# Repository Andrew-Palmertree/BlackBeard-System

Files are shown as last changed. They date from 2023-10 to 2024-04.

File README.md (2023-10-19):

# Blackbeard-System
This code is for our secure package delivery system, The Blackbeard System. This code will include object and facial recognition along with code for our servo control.

The idea behind Blackbeard is that it will allow delivered packages to end up securely inside of your home versus being left on your porch or inside some clunky metal box. The BlackBeard system incorporates a front door with a package drop located in the lower half of the door, which will drop the package in front of the front door inside of the home. It can fit packages equal to or smaller than 18x20. A camera with the system will be used to detect delivery drivers using artificial intelligence. Upon detection, the chute will open automatically for the delivery driver. The delivery man can put your package inside, then it will sense when no more packages are being delivered and automatically close, dropping the packages inside of the Blackbeard owner’s home. 
This product has space in quite a large market, to be installed on existing homes by DIYers or professional installation by contractors, or with over 1.8 million houses being built a year. This can also be installed on homes being newly built. As a company we will offer basic dimensions and different door materials, or interested customers can request custom dimensions to match their home.
The biggest areas of focus on this project are being able to depict delivery drivers using object recognition and interfacing the servo motors that control the package slip at the bottom of the front door. 
Time permitting, we would also like to implement a type of keyless entry into the home. This method would involve facial recognition of residents (utilizing the same camera for package deliveries) and/or a wireless entry system that unlocks the door when a keyfob is within proximity of the door (similar to keyless entry on modern automobiles). Despite our desire to add this additional feature, the main focus of the project is to get the package delivery system fully functional before pursuing any additional features. 

The goal of our proof of concept is to get the backend code fully functional with the servo motors, camera, & motion sensor interfaced properly with the Raspberry Pi. We plan to use a Raspberry Pi 3b+ for demonstration purposes, and it is likely we will fabricate our own PCB with a microcontroller when it comes time to create our prototype. We plan to implement computer vision with the camera and Raspberry Pi to begin training our system to detect delivery drivers and to recognize different faces. The system will be programmed using either Python or C++ depending on the route we choose to take in terms of an object recognition library. The primary goal is to get the package delivery system functional first, and time permitting we will pursue our secondary goal of creating a functional keyless entry system into the home. Below is a shortened, itemized list of what we want to be able to accomplish in our proof of concept. More detail into the major components is covered later on in this section. It is worth noting that we plan on testing all the components individually.
- Successfully interface components with Raspberry Pi
- Train a neural network to recognize delivery drivers with packages
- Camera is able to transmit real-time images to the Raspberry Pi
- Be able to trigger opening/closing of the package chute upon detection of a delivery driver
- Motion sensor is able to successfully detect motion inside the package chute
- After a period of time with no new motion detected, the chute will close

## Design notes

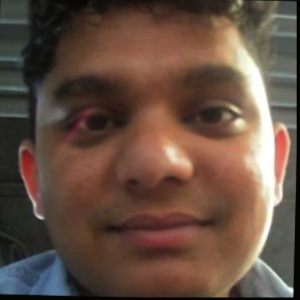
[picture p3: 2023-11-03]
Face_Recognition/pubfig/train/Parbin/cascade_images4_49.jpg

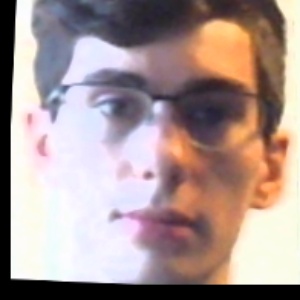
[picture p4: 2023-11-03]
Face_Recognition/Andrew/Andrew_cropped/cascade_images17_35.jpg

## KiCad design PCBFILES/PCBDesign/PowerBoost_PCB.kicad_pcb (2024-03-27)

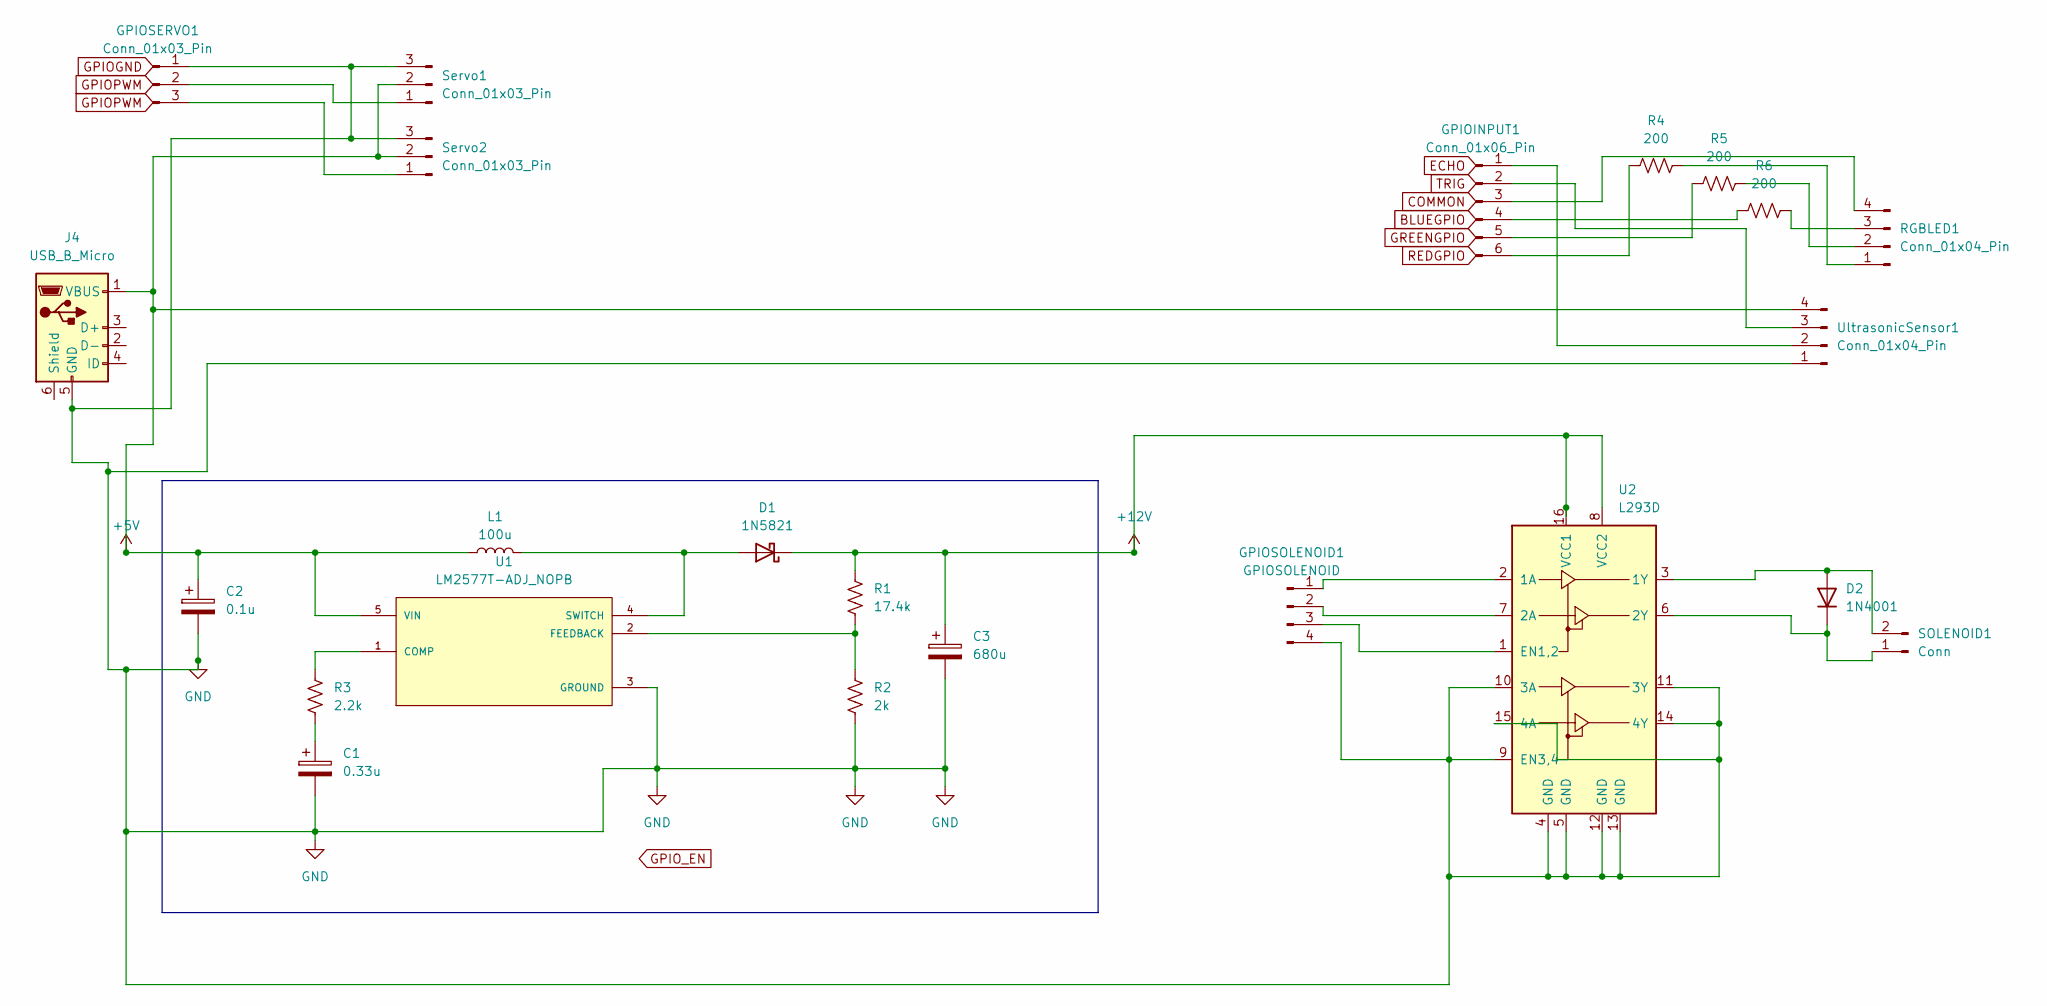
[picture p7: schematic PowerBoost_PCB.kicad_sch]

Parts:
C1: 0.33u; CP_Radial_D5.0mm_P2.50mm
C2: 0.1u; CP_Radial_D5.0mm_P2.50mm
C3: 680u; CP_Radial_D10.0mm_P5.00mm
D1: 1N5821; D_DO-201AD_P15.24mm_Horizontal
D2: 1N4001; D_DO-41_SOD81_P10.16mm_Horizontal
GPIOINPUT1: Conn_01x06_Pin
GPIOSERVO1: Conn_01x03_Pin
GPIOSOLENOID1: GPIOSOLENOID; JST_EH_B4B-EH-A_1x04_P2.50mm_Vertical
J4: USB_B_Micro
L1: 100u; L_Radial_D8.7mm_P5.00mm_Fastron_07HCP
R1: 17.4k; R_Axial_DIN0204_L3.6mm_D1.6mm_P7.62mm_Horizontal
R2: 2k; R_Axial_DIN0204_L3.6mm_D1.6mm_P7.62mm_Horizontal
R3: 2.2k; R_Axial_DIN0204_L3.6mm_D1.6mm_P7.62mm_Horizontal
R4, R5, R6: 200; R_Axial_DIN0204_L3.6mm_D1.6mm_P7.62mm_Horizontal
RGBLED1: Conn_01x04_Pin
SOLENOID1: Conn; JST_EH_B2B-EH-A_1x02_P2.50mm_Vertical
Servo1, Servo2: Conn_01x03_Pin
U1: LM2577T-ADJ_NOPB; VREG_LM2577T-ADJ_NOPB; PARTREV D
U2: L293D; DIP-16_W7.62mm
UltrasonicSensor1: Conn_01x04_Pin

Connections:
+5V: C2.1, J4.1 (VBUS), L1.1, Servo1.2, Servo2.2, U1.5 (VIN), UltrasonicSensor1.4
+12V: C3.1, D1.1 (K), R1.1, U2.8 (VCC2), U2.16 (VCC1)
GND: C1.2, C2.2, C3.2, GPIOSERVO1.1, GPIOSOLENOID1.4, J4.5 (GND), R2.2, Servo1.3, Servo2.3, U1.3 (GROUND), U2.4 (GND), U2.5 (GND), U2.9 (EN3,4), U2.10 (3A), U2.11 (3Y), U2.12 (GND), U2.13 (GND), U2.14 (4Y), U2.15 (4A), UltrasonicSensor1.1
unnamed: C1.1, R3.2
unnamed: D1.2 (A), L1.2, U1.4 (SWITCH)
unnamed: D2.2 (A), SOLENOID1.2, U2.3 (1Y)
unnamed: D2.1 (K), SOLENOID1.1, U2.6 (2Y)
unnamed: GPIOINPUT1.1, UltrasonicSensor1.2
unnamed: GPIOINPUT1.2, UltrasonicSensor1.3
unnamed: GPIOINPUT1.3, RGBLED1.4
unnamed: GPIOINPUT1.4, R6.1
unnamed: GPIOINPUT1.5, R5.2
unnamed: GPIOINPUT1.6, R4.1
unnamed: GPIOSERVO1.2, Servo1.1
unnamed: GPIOSERVO1.3, Servo2.1
unnamed: GPIOSOLENOID1.1, U2.2 (1A)
unnamed: GPIOSOLENOID1.2, U2.7 (2A)
unnamed: GPIOSOLENOID1.3, U2.1 (EN1,2)
unnamed: R4.2, RGBLED1.1
unnamed: R5.1, RGBLED1.2
unnamed: R6.2, RGBLED1.3
unnamed: R3.1, U1.1 (COMP)
unnamed: R1.2, R2.1, U1.2 (FEEDBACK)

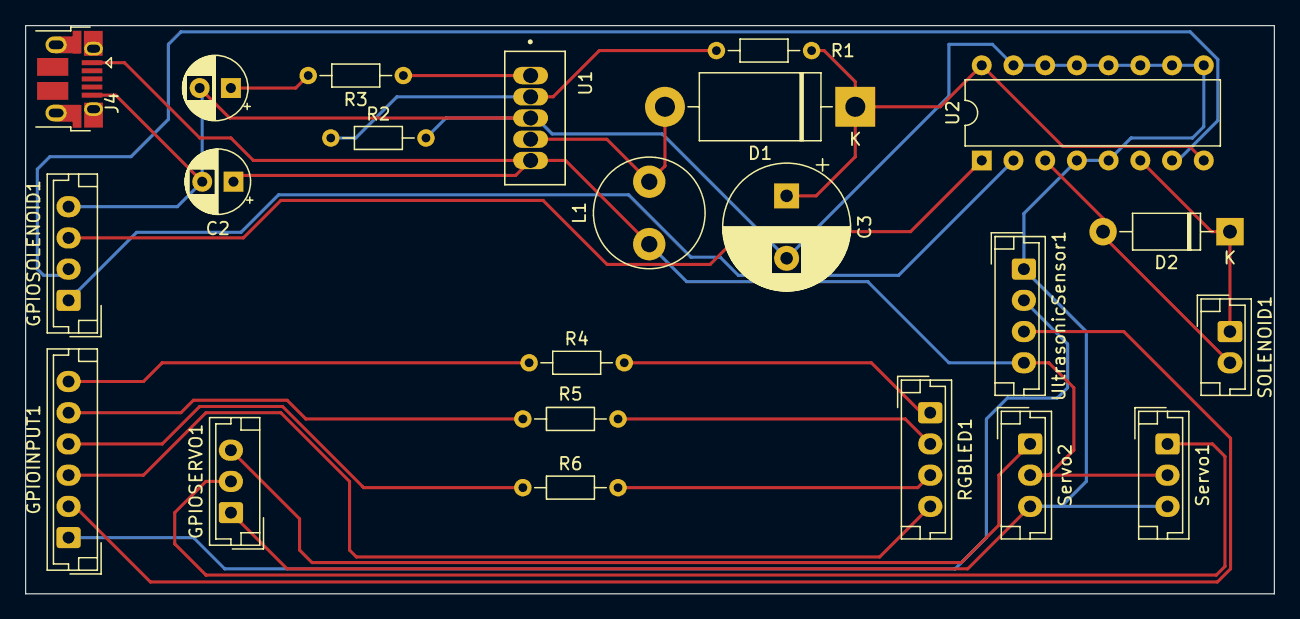
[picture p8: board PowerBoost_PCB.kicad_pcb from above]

Board: 2 copper layers, 100.0 x 45.5 mm, 23 parts (0 on the bottom side), 23 nets.

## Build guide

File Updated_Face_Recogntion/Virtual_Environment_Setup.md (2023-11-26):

#### Prepared by Andrew Palmertree for Senior Project Group Fall 2023

# UPDATED⚠️ Virtual Environment and Dependencies Setup
### This guide will allow you to install tensorflow 2.10.0,opencv 4.7.0.72, numpy 1.26.2, flatbuffers 2.0, keras_vggface, and keras_apptications.

### Note, using VNC and WinSCP will help you setup and use your reaspberry pi in the future. Instructions on how to setup VNC are at the bottom.

## 1. Project Initial Setup
### This step will get the raspberry pi working before installing the packages we need for the machine learning environment

#### This is import first step:
Make sure you are using Bullseye 11 64 bit legacy.

Go to this website incase you need to download the 64 bit OS:

https://www.raspberrypi.com/software/operating-systems/#raspberry-pi-os-64-bit

Once you have the OS installed and setup, go ahead and verify you have the Bullseye 11 OS installed:

```$cat /etc/os-release```

Look for the version_id and version to see what version of the OS you are running. If you are not running the Bullseye 11 OS then stop and install and flash the Bullseye 11 legacy OS version onto your Pi.

#### If we decide we are not using a USB camera but the socket camera you can enable it by following these steps:

1. ```$sudo raspi-config ```
2. Select option one "1 System Options"
3. Selcet option one "I1 Legacy Camera"
4. Select Enable

#### Now update your system:
```
$sudo apt-get update 
$sudo apt-get upgrade 
```
and then restarted the Pi to update all the packages installed.

#### Downgrade Python Version to 3.9.2
The next step in setting up the Raspberry Pi is to ensure that the dependencies and packages are compatible with each other. To achieve this, I downgraded Python to version 3.9.2. To do so, I ran the following commands: 

```
# Downloads Pyenv tool script and runs it in bash
$ curl https://pyenv.run | bash
$ sudo nano ~/.bashrc 
```

In the .bashrc file, I added the following lines at the end of the file: 
```
# adds /.pyenv/bin directory to your PATH environment variable
export PATH="$HOME/.pyenv/bin:$PATH" 
```
Pyenv is initialized and the shell's PATH and other environment variables are modified to prepare the shell for usage with Pyenv's shims. 

```
eval "$(pyenv init --path)"

# used to manage virtual environments
eval "$(pyenv virtualenv-init -) 
 ```

 I then restarted the terminal and installed the following packages: 
 
 ```
 $ sudo apt-get install --yes libssl-dev zlib1g-dev libbz2-dev libreadline-dev libsqlite3-dev llvm libncurses5-dev libncursesw5-dev xz-utils tk-dev libgdbm-dev lzma lzma-dev tcl-dev libxml2-dev libxmlsec1-dev libffi-dev liblzma-dev wget make opens 
 ```

Next, I updated pyenv and installed python 3.7.12: 
```
$ pyenv update
$ pyenv install –list
$ pyenv install 3.9.2 
```

After installing python 3.7.12, I set my project folder to python 3.7.12 with the following commands: 

```
$ mkdir project
$ cd project
$ pyenv local 3.9.2
$ python -V 
```
I got the following results from running python -V.

<img width="503" alt="python_version" src="https://github.com/w-410berry/Blackbeard-System/assets/66178969/9aa92d15-ab7a-4712-9a47-9c83f6dc6488">

## 2. Install and activate the virtual environment
We want to create a virtual environment so that we can isolate the Python environment and install specific packages for the project without affecting the root environment. Virtual environments are particularly useful for testing, creating backups, and enhancing security. To create a virtual environment for our real-time handwritten recognition project, I used the following commands:

```
// Creates the virtual environment
$ python3 -m pip install virtualenv
$ python3 -m virtualenv env

// activate the environment
$ source env/bin/activate 
```

Then I installed some necessary dependencies: 

```
$ sudo apt-get install -y libhdf5-dev libc-ares-dev libeigen3-dev gcc gfortran libgfortran5 libatlas3-base libatlas-base-dev libopenblas-dev libopenblas-base libblas-dev liblapack-dev cython3 libatlas-base-dev openmpi-bin libopenmpi-dev python3-dev build-essential cmake pkg-config libjpeg-dev libtiff5-dev libpng-dev libavcodec-dev libavformat-dev libswscale-dev libv4l-dev libxvidcore-dev libx264-dev libfontconfig1-dev libcairo2-dev libgdk-pixbuf2.0-dev libpango1.0-dev libgtk2.0-dev libgtk-3-dev libhdf5-serial-dev libhdf5-103 libqt5gui5 libqt5webkit5 libqt5test5 python3-pyqt5 
```

After installing the necessary dependencies, we can activate the virtual environment in the project directory by using the following command:

```
$source env/bin/activate
```

Below is a demonstration that the virtual environment can be activated through the project directory.

![image](https://github.com/w-410berry/Blackbeard-System/assets/66178969/0ebe2ba1-08fd-4eb6-865a-93bf20dab3c8)

## 3. Installing Packages in Virtual Environment 
Next, we must install the packages required for the virtual environment.To install TensorFlow 2.10.0.

You can get the tensorflow 2.10.0 file from the following commands:

```
# uninstall any previous versions of TensorFlow
$ python3 -m pip uninstall tensorflow

# Install TensorFlow 2.10.0 with the wheel file
$ pip install tensorflow==2.10.0

# Fix any other dependency issues you may have before going forward.
```

#### I then installed OpenCV:
#### Note the following
#### Time command keeps track how long your command is running and will print the results at the end
#### There are many version of opencv
1. opencv-python
2. opencv-contrib-python
3. opencv-python-headless
4. opencv-contrib-python-headless
#### Options 3 and 4 are for server (headless) environments
#### Options 1 and 2 for standard desktop environments
#### opencv-python: Main modules
#### opencv-contrib-python: Full package which contains both main modules and extra modules
#### for the cascade facial recognition we need the opencv-contrib-python:
```
# Install opencv-contrib-python (took 152 minutes on the raspberry pi 4 32 bit but with 64 bit took less than 2 minutes)
# As long as there is no error and says building the wheel then just keep waiting
$ time pip install "opencv-contrib-python<4.8"

# I then upgrade numpy to be compatible with cv2 to version 1.26.0.
$ pip install numpy==1.26.2

# Install some packages for the ResNet model:
pip install git+https://github.com/rcmalli/keras-vggface.git

pip install keras_apptications

Now to be able to convert from tensorflow to tensorflow lite I had to change flatbuffers version to 2.0:
pip install flatbuffers==2.0

# Now that TensorFlow and OpenCV is installed, I verified that I could import them by running the following commands in the Python3 shell:
$ python3 
>>> import tensorflow as tf
>>> tf._version_
>>> import cv2
>>> cv2._version_
>>> import keras_vggface
# to exit run exit() or quit()
```

If you are using the a pi camera install their packages:
```
# install picamera package
$ pip install picamera
```

## 4. (optional) Setting up VNC to see you raspberry pi display on your laptop

Make sure VNC is on your Pi. There should be an icon on the top right with the big "R" symbol or go to the "internet" tab at the top left and click VNC viewer. 
If VNC viewer is not shown then follow a online guide to install VNC viewer sever on the Pi. It should already be installed on your Pi.

<img width="546" alt="VNC_1" src="https://github.com/w-410berry/Blackbeard-System/assets/66178969/32ad97e4-4dc8-4e61-ad5d-160cbe421f27">

Once you know VNC server is installed then follow the following steps:

#### ON THE RASPBERRY PI:

To enable VNC, I entered 
```
$sudo raspi-config
```
in the terminal and navigated to "Interface Options" >>> "VNC" >>> "enable".

Note: To see the Pi Camera remotely I had to go to the server Raspberry Pi VNC and press: 
#### menu (three lines on the top right) >>> options >>> Troubleshooting >>> Enable direct capture mode.

<img width="540" alt="VNC_2" src="https://github.com/w-410berry/Blackbeard-System/assets/66178969/914d3148-9e92-4146-9e23-2282fc0cee6c">

#### ON THE COMPUTER:

Next, I installed the VNC client on my desktop computer, which enabled my laptop to connect to the Raspberry Pi VNC server. After installing the VNC client on my laptop, I created a new connection by navigating to 
#### "File" >>> "New Connection" in the VNC client. 
#### OR press (ctrl + n)
I then entered the Raspberry Pi server's IP address, hostname, and password to establish the connection. Finally, I was able to successfully connect to the server and view the Raspberry Pi desktop screen.  

## Thank you! I hope you were able to follow along and complete the setup.

# Happy Coding :) 🙌

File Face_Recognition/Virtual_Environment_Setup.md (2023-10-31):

#### Prepared by Andrew Palmertree for Senior Project Group Fall 2023

# Virtual Environment and Dependencies Setup
### This guide will allow you to install tensorflow 2.5.0, Keras 2.4.3, and opencv 4.7.0.72

### Note, using VNC and WinSCP will help you setup and use your reaspberry pi in the future. Instructions on how to setup VNC are at the bottom.

## 1. Project Initial Setup
### This step will get the raspberry pi working before installing the packages we need for the machine learning environment

#### This is import first step:
Make sure you have the latest version of the Raspberry Pi OS. As of creating this I am using Bullseye 11:

```$cat /etc/os-release```

Look for the version_id and version to see what version of the OS you are running. If you are not running the lastest OS then stop and install and flash the newest OS version onto your Pi.

#### If we decide we are not using a USB camera but the socket camera you can enable it by following these steps:

1. ```$sudo raspi-config ```
2. Select option one "1 System Options"
3. Selcet option one "I1 Legacy Camera"
4. Select Enable

#### Now update your system:
```
$sudo apt-get update 
$sudo apt-get upgrade 
```
and then restarted the Pi to update all the packages installed.

#### Downgrade Python Version to 3.7.12
The next step in setting up the Raspberry Pi is to ensure that the dependencies and packages are compatible with each other. To achieve this, I downgraded Python to version 3.7.12. To do so, I ran the following commands: 

```
# Downloads Pyenv tool script and runs it in bash
$ curl https://pyenv.run | bash
$ sudo nano ~/.bashrc 
```

In the .bashrc file, I added the following lines at the end of the file: 
```
# adds /.pyenv/bin directory to your PATH environment variable
export PATH="$HOME/.pyenv/bin:$PATH" 
```
Pyenv is initialized and the shell's PATH and other environment variables are modified to prepare the shell for usage with Pyenv's shims. 

```
eval "$(pyenv init --path)"

# used to manage virtual environments
eval "$(pyenv virtualenv-init -) 
 ```

 I then restarted the terminal and installed the following packages: 
 
 ```
 $ sudo apt-get install --yes libssl-dev zlib1g-dev libbz2-dev libreadline-dev libsqlite3-dev llvm libncurses5-dev libncursesw5-dev xz-utils tk-dev libgdbm-dev lzma lzma-dev tcl-dev libxml2-dev libxmlsec1-dev libffi-dev liblzma-dev wget make opens 
 ```

Next, I updated pyenv and installed python 3.7.12: 
```
$ pyenv update
$ pyenv install –list
$ pyenv install 3.7.12 
```

After installing python 3.7.12, I set my project folder to python 3.7.12 with the following commands: 

```
$ mkdir project
$ cd project
$ pyenv local 3.7.12
$ python -V 
```
I got the following results from running python -V.

<img width="503" alt="python_version" src="https://github.com/w-410berry/Blackbeard-System/assets/66178969/9aa92d15-ab7a-4712-9a47-9c83f6dc6488">

## 2. Install and activate the virtual environment
We want to create a virtual environment so that we can isolate the Python environment and install specific packages for the project without affecting the root environment. Virtual environments are particularly useful for testing, creating backups, and enhancing security. To create a virtual environment for our real-time handwritten recognition project, I used the following commands:

```
// Creates the virtual environment
$ python3 -m pip install virtualenv
$ python3 -m virtualenv env

// activate the environment
$ source env/bin/activate 
```

Then I installed some necessary dependencies: 

```
$ sudo apt-get install -y libhdf5-dev libc-ares-dev libeigen3-dev gcc gfortran libgfortran5 libatlas3-base libatlas-base-dev libopenblas-dev libopenblas-base libblas-dev liblapack-dev cython3 libatlas-base-dev openmpi-bin libopenmpi-dev python3-dev build-essential cmake pkg-config libjpeg-dev libtiff5-dev libpng-dev libavcodec-dev libavformat-dev libswscale-dev libv4l-dev libxvidcore-dev libx264-dev libfontconfig1-dev libcairo2-dev libgdk-pixbuf2.0-dev libpango1.0-dev libgtk2.0-dev libgtk-3-dev libhdf5-serial-dev libhdf5-103 libqt5gui5 libqt5webkit5 libqt5test5 python3-pyqt5 
```

After installing the necessary dependencies, we can activate the virtual environment in the project directory by using the following command:

```
$source env/bin/activate
```

Below is a demonstration that the virtual environment can be activated through the project directory.

![image](https://github.com/w-410berry/Blackbeard-System/assets/66178969/0ebe2ba1-08fd-4eb6-865a-93bf20dab3c8)

## 3. Installing Packages in Virtual Environment 
Next, we must install the packages required for the virtual environment.To install TensorFlow, I used WinSCP software to transfer a file called tensorflow-2.5.0-cp37-none-linux_armv7l.whl from my laptop to the Raspberry Pi project folder. The wheel file contains all the necessary files to install TensorFlow 2.5.0 on an ARM7L embedded system.

you can get the tensorflow 2.5.0 file from here:
https://drive.google.com/uc?export=download&id=10rNYmGu2V9PFCcSRUEp_6H8j9WeKPusR

Now transfer that file to your rasberry pi's projecy folder.

To verify that TensorFlow file is in your project directory use the following command in the project directory: 

```
$ls | grep tensorflow* 
```

Now use the wheel file to install TensorFlow. 
```
# uninstall any previous versions of TensorFlow
$ python3 -m pip uninstall tensorflow

# Install TensorFlow 2.5.0 with the wheel file
$ python3 -m pip install tensorflow-2.5.0-cp37-none-linux_armv7l.whl

# Once TensorFlow is installed, I ran the following command to solve a compatibility issue: (This was needed for tensorflow 2.4.0, for tensorflow 2.5.0 I would still try running the following command solve any issues that come up)

$ pip uninstall h5py; HDF5_VERSION=1.10.6 pip install --no-binary=h5py h5py==3.1.0

# two issues that I ran into and helped fix the dependency errors was the following commands

$ pip uninstall platformdirs
$ pip install platformdirs==2.5.0

$ pip uninstall typing-extensions
$ pip install typing-extensions==3.7.4

# Fix any other dependency issues you may have before going forward.
```

#### I then installed OpenCV:
#### Note the following
#### Time command keeps track how long your command is running and will print the results at the end
#### There are many version of opencv
1. opencv-python
2. opencv-contrib-python
3. opencv-python-headless
4. opencv-contrib-python-headless
#### Options 3 and 4 are for server (headless) environments
#### Options 1 and 2 for standard desktop environments
#### opencv-python: Main modules
#### opencv-contrib-python: Full package which contains both main modules and extra modules
#### for the cascade facial recognition we need the opencv-contrib-python:
```
# Install opencv-contrib-python (took 152 minutes on the raspberry pi 4)
# As long as there is no error and says building the wheel then just keep waiting
$ time python3 -m pip install "opencv-contrib-python<4.8"

I then upgrade numpy to be compatible with cv2.
$ pip install --upgrade numpy

# Now that TensorFlow and OpenCV is installed, I verified that I could import them by running the following commands in the Python3 shell:
$ python3 // run in the command prompt to open up the Python shell
>>> import tensorflow as tf
>>> tf._version_
>>> import cv2
>>> cv2._version_
# to exit run exit() or quit()
```

If you are using the a pi camera install their packages:
```
# install picamera package
$ pip install picamera
```

Now to install Keras for Tensorflow 2.5.0:
```
$ pip uninstall keras
$ pip install keras==2.4.3

Make sure everything is working with no errors:
$ python3 // run in the command prompt to open up the Python shell
>>> import tensorflow as tf
>>> tf._version_
>>> import cv2
>>> cv2._version_
>>> import keras
>>> import numpy as np
# to exit run exit() or quit()
```

## 4. (optional) Setting up VNC to see you raspberry pi display on your laptop

Make sure VNC is on your Pi. There should be an icon on the top right with the big "R" symbol or go to the "internet" tab at the top left and click VNC viewer. 
If VNC viewer is not shown then follow a online guide to install VNC viewer sever on the Pi. It should already be installed on your Pi.

<img width="546" alt="VNC_1" src="https://github.com/w-410berry/Blackbeard-System/assets/66178969/32ad97e4-4dc8-4e61-ad5d-160cbe421f27">

Once you know VNC server is installed then follow the following steps:

#### ON THE RASPBERRY PI:

To enable VNC, I entered 
```
$sudo raspi-config
```
in the terminal and navigated to "Interface Options" >>> "VNC" >>> "enable".

Note: To see the Pi Camera remotely I had to go to the server Raspberry Pi VNC and press: 
#### menu (three lines on the top right) >>> options >>> Troubleshooting >>> Enable direct capture mode.

<img width="540" alt="VNC_2" src="https://github.com/w-410berry/Blackbeard-System/assets/66178969/914d3148-9e92-4146-9e23-2282fc0cee6c">

#### ON THE COMPUTER:

Next, I installed the VNC client on my desktop computer, which enabled my laptop to connect to the Raspberry Pi VNC server. After installing the VNC client on my laptop, I created a new connection by navigating to 
#### "File" >>> "New Connection" in the VNC client. 
#### OR press (ctrl + n)
I then entered the Raspberry Pi server's IP address, hostname, and password to establish the connection. Finally, I was able to successfully connect to the server and view the Raspberry Pi desktop screen.  

## Thank you! I hope you were able to follow along and complete the setup.
This completes the guide of setting up a virtual environment on a raspberry pi and installing tensorflow 2.5.0, keras 2.4.3, opencv-contrib-python 4.7.0.72, and setting up the client and server VNC connection. 

# Happy Coding :) 🙌

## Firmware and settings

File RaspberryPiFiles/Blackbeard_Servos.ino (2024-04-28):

#include <Servo.h>
#include <string.h>

Servo frontservo;
Servo backservo;

int front_angle;
int back_angle;

int FRONT_OPEN_ANGLE = 105;
int FRONT_CLOSE_ANGLE = 45;
int BACK_OPEN_ANGLE = 165;
int BACK_CLOSE_ANGLE = 225;

float US_TO_PULSE = 2000/270;

int angle_to_pwm(int input_angle){
  // converts 270 angle to 180, so that the same PWM can be applied
  return (input_angle * US_TO_PULSE) + 500;
}

void move_servo(int new_angle, char frontOrBack){

    int pulse_width = angle_to_pwm(new_angle);

    // init local variables
    Servo servoMotor;
    int old_angle;

    // check if the front or back servo will be moved
    if(frontOrBack=='f'){
      servoMotor = frontservo;
      old_angle = front_angle;
    } else if(frontOrBack=='b'){
      servoMotor = backservo;
      old_angle = back_angle;
    }

    while(new_angle != old_angle) {

      if(new_angle > old_angle) {
        // INCREASING SERVO ANGLE
        old_angle += 1;
      } else if(new_angle < old_angle) {
        // DECREASING SERVO ANGLE
        old_angle -= 1;
      }
      // move servo and sleep for set time
      servoMotor.writeMicroseconds(angle_to_pwm(old_angle));
      delay(50); 
    }

    // UPDATE ANGLE VARIABLE
    if(frontOrBack=='f'){
      front_angle = old_angle;
    } else if(frontOrBack=='b'){
      back_angle = old_angle;
    }
    
}

void setup() {
  Serial.begin(115200);

  frontservo.attach(14);  // gpio17
  backservo.attach(17);  // gpio15
  

  // init servos
  frontservo.write(angle_to_pwm(FRONT_CLOSE_ANGLE));
  backservo.write(angle_to_pwm(BACK_CLOSE_ANGLE));

  front_angle = FRONT_CLOSE_ANGLE;
  back_angle = BACK_CLOSE_ANGLE;

}

void loop() {
  // put your main code here, to run repeatedly:
  if(Serial.available() > 0) {
    String serialData = Serial.readString();
    //serialData = Serial.readStringUntil(END_SERIAL_READ);
    Serial.println(serialData);
    for(int i = 0; i < serialData.length(); i++) {
      Serial.write(serialData[i]);
    }

    if(serialData=="front_open"){
      move_servo(FRONT_OPEN_ANGLE, 'f');
    } else if(serialData=="front_close"){
      move_servo(FRONT_CLOSE_ANGLE, 'f');
    } else if(serialData=="back_open"){
      move_servo(BACK_OPEN_ANGLE, 'b');
    } else if(serialData=="back_close"){
      move_servo(BACK_CLOSE_ANGLE, 'b');
    }

  }
}

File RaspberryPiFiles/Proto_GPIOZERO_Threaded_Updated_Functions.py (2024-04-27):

from gpiozero import DistanceSensor, AngularServo, RGBLED, DigitalOutputDevice
import time
import threading

################################################# CONSTANT DECLARATIONS

############################# GPIO Pin Declarations
RED_PIN = 1
GREEN_PIN = 7
BLUE_PIN = 8
TRIG_PIN = 20
ECHO_PIN = 21
FRONT_SERVO_PIN = 12
BACK_SERVO_PIN = 13
SOLENOID_EN_PIN = 0
SOLENOID_EXTEND_PIN = 5
SOLENOID_RETRACT_PIN = 6

############################# Mathematical Constants
US_TO_DUTY = 0.037037

############################# Timing Constants
TIME_SLEEP_DIST_SENS = 0.5
TIME_NO_MOVEMENT = 5
TIME_BEFORE_DIST_SENS = 3
TIME_REAR_CHUTE_OPEN = 10
TIME_BETWEEN_LOCK_UNLOCK = 3

############################# Servo Angle Constants
FRONT_OPEN_ANGLE = -35
FRONT_CLOSE_ANGLE = -135
BACK_OPEN_ANGLE = 30
BACK_CLOSE_ANGLE = 135
STEPS = 100
BACK_STEPS = 250
FRONTSTEP_SIZE = abs((FRONT_OPEN_ANGLE-FRONT_CLOSE_ANGLE)/STEPS)
FRONTBACK_STEP_SIZE = abs((FRONT_OPEN_ANGLE-FRONT_CLOSE_ANGLE)/BACK_STEPS)

BACKSTEP_SIZE = abs((BACK_OPEN_ANGLE-BACK_CLOSE_ANGLE)/STEPS)
BACKBACK_STEP_SIZE = abs((BACK_OPEN_ANGLE-BACK_CLOSE_ANGLE)/BACK_STEPS)

############################# LED Color Constants
CHUTE_LED_COLOR = "blue"
DOOR_LED_COLOR = "green"


################################################ GPIO INITIALIZATION

#Updated for RPI 5
ultrasonic = DistanceSensor(trigger = TRIG_PIN, echo = ECHO_PIN)
frontServo = AngularServo(FRONT_SERVO_PIN, initial_angle = FRONT_CLOSE_ANGLE, min_angle=-135, max_angle=135, min_pulse_width=0.0005, max_pulse_width=0.0025, pin_factory=factory)
backServo = AngularServo(BACK_SERVO_PIN, initial_angle = BACK_CLOSE_ANGLE, min_angle=-135, max_angle=135, min_pulse_width=0.0005, max_pulse_width=0.0025, pin_factory=factory)
led = RGBLED(red = RED_PIN, green = GREEN_PIN, blue = BLUE_PIN)
solenoidEn = DigitalOutputDevice(SOLENOID_EN_PIN)
extend = DigitalOutputDevice(SOLENOID_EXTEND_PIN)
retract = DigitalOutputDevice(SOLENOID_RETRACT_PIN)

################################################ THREADING FUNCTIONS

def create_chute_thread():
	return threading.Thread(target=activate_chute)

def create_door_thread():
	return threading.Thread(target=activate_door)

################################################ SERVO FUNCTIONS

def front_servo_open():
	"""
	Controls the speed at which the front servo motor is able to open
	"""
	CURRENT_POS = frontServo.angle;
	
	#For loop to slowly move the motor
    	for _ in range(STEPS):
        	CURRENT_POS += FRONTSTEP_SIZE
        	frontServo.angle = CURRENT_POS
        	time.sleep(.02)
    	#Ensures it gets to the desired angle
    	frontServo.angle = FRONT_OPEN_ANGLE

def front_servo_close():
	"""
	Controls the speed at which the front servo motor is able to close
	"""
    	CURRENT_POS = frontServo.angle;
    
    	#For loop to slowly move the motor
    	for _ in range(BACK_STEPS):
        	CURRENT_POS -= FRONTBACK_STEP_SIZE
        	if (CURRENT_POS <= -135):
            		frontServo.angle = FRONT_CLOSE_ANGLE
            		break
        	else:
            		frontServo.angle = CURRENT_POS
            		time.sleep(.02)
            		print(CURRENT_POS)
			
    	#Ensures it gets to the desired angle
    	frontServo.angle = FRONT_CLOSE_ANGLE

def back_servo_open():
	"""
	Controls the speed at which the back servo is able to open
	"""
    	CURRENT_POS = backServo.angle;
    
   	#For loop to slowly move the motor
    	for _ in range(STEPS):
        	CURRENT_POS -= BACKSTEP_SIZE
        	backServo.angle = CURRENT_POS
        	time.sleep(.02)
    	#Ensures it gets to the desired angle
    	backServo.angle = BACK_OPEN_ANGLE

def back_servo_close():
	"""
	Controls the speed at which the back servo is able to close
	"""
    	CURRENT_POS = backServo.angle;
    
    	#For loop to slowly move the motor
    	for _ in range(BACK_STEPS):
        	CURRENT_POS += BACKBACK_STEP_SIZE
        	if (CURRENT_POS >= 135):
            		backServo.angle = BACK_CLOSE_ANGLE
            		break
        	else:
            		backServo.angle = CURRENT_POS
            		time.sleep(.02)
            		print(CURRENT_POS)
    	#Ensures it gets to the desired angle
    	backServo.angle = BACK_CLOSE_ANGLE


################################################ SOLENOID FUNCTIONS

def solenoid_pulse(SOLENOID_PIN):
	"""
	Sends a pulse to the specified solenoid terminal to retract or
	extend the solenoid. Depending on the pulse that is sent, the
	lenght of the pulse will be set and the pulse will be sent
	to the solenoid and either extend or retract
	"""

	solenoidEn.on()

	PULSE_TIME = 0.04

	# define length of pulse sent to the solenoid
	if SOLENOID_PIN == extend:
		PULSE_TIME = 0.04
		print("EXTEND")
	elif SOLENOID_PIN == retract:
		PULSE_TIME = 0.07
		print("RETRACT")

	print(f"PULSE TIME = {PULSE_TIME}")

	SOLENOID_PIN.on()
	time.sleep(PULSE_TIME)
	SOLENOID_PIN.off()

def solenoid_extend():
	"""
	Extends the solenoid, putting the door into the locked postion
	"""
	solenoid_pulse(extend)
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

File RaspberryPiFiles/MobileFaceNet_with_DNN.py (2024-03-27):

#############################################################################################
# Project Name: BlackBeard
# Created by: Parbin Darji, Will Fortenberry, Andrew Palmertree, Imanol  Perales, Justin Romanowski
#
# Script name: MobileFaceNet_with_DNN.py
#
# Date: March 9, 2024
# Version: 1.0.0
# 
# Requirments:
#     - python 3.9.2
#     - check the requirement.txt file for specific packages
#
# Description:
#     The MobileFaceNet_with_DNN script is for the BlackBeard project to be used on the microcontroller side to
#     detect faces and objects.
#
#      Object list: amazon logo, amazon delivery uniform, delivery car, fedex logo,
#                   fedex uniform, package, person, safety vest, ups logo, ups uniform
#                   usps logo, and usps delivery uniform
#
# Notes:
# The object recognition runs on the Google Corel TPU USB accelerator
# The face recognition runs on the microcontroller CPU for better accuracy 
#
#############################################################################################


#============================================================================================
# Import the necessary package libraries
#============================================================================================
import os
import argparse

import cv2
import numpy as np
import sys
import time
from threading import Thread, Event
import importlib.util
from tflite_runtime.interpreter import Interpreter
from tflite_runtime.interpreter import load_delegate
from PIL import Image
import glob
import requests
import subprocess
import json


#============================================================================================
# Initialize variables 
#============================================================================================


latest_version_converted = -1  # Shared variable to store the latest version
update_event = Event()  # Event to signal when to update the latest version
current_version = -1 # Used to keep track if there is a new trained tflite file available

# Load the pre-trained model and configuration for DNN face extraction
modelFile = "res10_300x300_ssd_iter_140000.caffemodel"
configFile = "deploy.prototxt.txt"
net = cv2.dnn.readNetFromCaffe(configFile, modelFile)

# Get current working directory
current_directory = os.getcwd()

# IP address of server
# IP_ADDRESS = '192.168.2.203'
IP_ADDRESS = '10.101.169.96'

# Used to determine to send face and object prediction data to the server
send_live_image = False

# Used to store the object and face recognition data 
face_predictions = []
object_predictions = []

frame_rate = 5  # Target frame rate, 5 frames per second
previous_time = time.time() # Used for checking the time for upload live feed to server for the app

#============================================================================================
# Define used functions
#============================================================================================


#############################################################################################
# Preprocesses an image for input to a neural network
#############################################################################################
def preprocess(img):

    # Normalize pixel values to [-1, 1]
    img = (img.astype("float32") - 127.5) / 128.0
    # Add batch dimension of batch size of 1
    img = np.expand_dims(img, axis=0)
    return img


#############################################################################################
# Function to load the TFLite model capable of running on the Edge TPU
#############################################################################################
def load_tflite_model(model_path):
    
    interpreter = Interpreter(model_path=model_path,
                                  experimental_delegates=[load_delegate('libedgetpu.so.1.0')])
    interpreter.allocate_tensors()
    return interpreter


#############################################################################################
# Function to detect faces and draw bounding boxes around the faces with labels
#############################################################################################
def detect_bounding_box(vid, interpreter):
    
    # Get the height and width of the frame
    h, w = vid.shape[:2]

    # Prepare the image for input to the DDN face extraction
    blob = cv2.dnn.blobFromImage(cv2.resize(vid, (300, 300)), 1.0, (300, 300), (104.0, 117.0, 123.0))

    # Set the input blob for the neural network
    net.setInput(blob)

    # Perform forward pass inference to detect faces
    detections = net.forward()

    # Draw bounding boxes around the detected faces
    for i in range(detections.shape[2]):
        confidence = detections[0, 0, i, 2]
        if confidence > 0.5:
            box = detections[0, 0, i, 3:7] * np.array([w, h, w, h])
            (x, y, x1, y1) = box.astype("int")
            cv2.rectangle(vid, (x, y), (x1, y1), (0, 0, 255), 2)

            # Region of Interest (ROI) for the detected face
            roi_color = vid[y:y1, x:x1]

            # Resize the detected face to the expected input size (96x112) the MobileFaceNet model
            face = cv2.resize(roi_color, (96, 112))

            # Preprocess the face image
            face = preprocess(face)

            # Run inference on the preprocessed face
            input_details = interpreter.get_input_details()
            output_details = interpreter.get_output_details()

        
            interpreter.set_tensor(input_details[0]['index'], face)
            interpreter.invoke()
            embedding_yzy = interpreter.get_tensor(output_details[0]['index'])

            embedding_yzy = embedding_yzy / np.expand_dims(np.sqrt(np.sum(np.power(embedding_yzy, 2), 1)), 1)
            
            prediction = 0
            
            # Directory where the Data_File_#.txt files will be stored 
            data_file = f"Models/dataBase/Data_File_{latest_version_converted}.txt"
            DATA_FILE_LOCATION = os.path.join(current_directory, data_file)
            
            # Latest Data File used to compare with the live image to determine if it's a known user in frame
            file_data = DATA_FILE_LOCATION
            print("Latest version: " + str(latest_version_converted))
            
            data = np.loadtxt(file_data)
            
            num_entries = data.shape[0]
            
            list_t = []
            
            # Directory where the labelmap_mobileFaceNet#.txt files will be stored 
            label_file = f"Models/Edge/labelmap_mobileFaceNet{latest_version_converted}.txt"
            LABEL_FILE_LOCATION = os.path.join(current_directory, label_file)
            
            # Label map file for known user classes names   
            labelmap_file = LABEL_FILE_LOCATION
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

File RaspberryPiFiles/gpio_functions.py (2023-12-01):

import RPi.GPIO as GPIO
import time


# Initialize GPIO pins
LOCK_PIN = 5 # pin x bcm 5
CHUTE_PIN = 22 # pin 37 bcm 22
TRIG_PIN = 18 # pin 12 bcm 18
ECHO_PIN = 12 # pin 32 bcm 12
GLED_PIN = 13 # pin x bcm 13
BLED_PIN = 26 # pin x bcm 26
CBUTTON_PIN = 20 # pin x bcm 20
LBUTTON_PIN = 21 # pin x bcm 21


def get_distance():
	"""
	Sends an ultrasonic trigger, listens for the echo, & calculates the distance.
	Returns distance.
	"""

	# send pulse to trigger pin to send ultrasound wave
	GPIO.output(TRIG_PIN,GPIO.HIGH)
	time.sleep(0.00001)
	GPIO.output(TRIG_PIN,GPIO.LOW)
	print("sent trigger")
	# start recording time & wait for ultrasound to return
	start_time = time.time()
	stop_time = time.time()

	print("waiting for echo")
	while GPIO.input(ECHO_PIN) == 0:
		start_time = time.time()
	while GPIO.input(ECHO_PIN) == 1:
		stop_time = time.time()

	print("calculating distance")
	# calculate time elapsed, then multiply by speed of sound
	dist = (stop_time - start_time) * 34300 / 2 # divide by 2 since pulse travels there and back
	return dist

def sense_movement():
	"""
	Senses for movement inside of the package chute to automatically close the chute. Holds the 
	program flow in a while loop until either max time elapsed or no objects are detected 
	inside of the package chute.
	"""

	dist_curr = get_distance()
	dist_prev = dist_curr

	start_time = time.time()
	timer = time.time()

	# TODO: when no movement is sensed for 5 seconds, then close the box
	# current function: closes when 5 seconds elapsed or movement detected

	movement_sensed = True
	closing_timer = 0
	present_timer = 0
	no_movement_time = 5 # time to wait for no movement in package chute before closing

	while (present_timer-closing_timer<no_movement_time):
		time.sleep(0.5)
		dist_prev = dist_curr # set prev distance to current
		dist_curr = get_distance()
		print(f"current dist: {dist_curr}\tprevois dist: {dist_prev}")
		movement_boolean = (dist_curr<dist_prev+4 and dist_prev-4<dist_curr)

		# analyze different scenarios while sensing for pack
		if movement_boolean and movement_sensed:
			# no movement detected & movement previously detected
			# start logging time that there is no movement inside chute
			closing_timer = time.time()
			present_timer = closing_timer
			movement_sensed = False

			print(f"no movement sensed! starting timing for closing..")
		elif movement_boolean and not movement_sensed:
			# no movement detected & no movement previously detected
			# continue polling, see if no movement detected for 5s
			present_timer = time.time()

			print(f"no movement sensed, time = {present_timer - closing_timer}")
		elif not movement_boolean and movement_sensed:
			# movement detected & movement previously detected
			# ensure timers still set at 0
			closing_timer = 0
			present_timer = 0

			print(f"movement detected in chute still")
		elif not movement_boolean and not movement_sensed:
			# movement detected & movement not previosly detected
			# reset timers & change movement_sensed variable
			closing_timer = 0
			present_timer = 0
			movement_sensed = True

			print(f"movement detected in chute1 reseting timers..")

def servo_write(angle,pwm_obj):
	"""
	Changes the angle of the servo motor. Desired angle passed in as argument
	"""

	# pwm ranges (0-10) + 2.5 --> 2.5-12.5
	# angle ranges 0-180
	pwm = (angle/18) + 2.5
	pwm_obj.ChangeDutyCycle(pwm)
	print(f"angle: {angle}\tpwm: {pwm}")

def led_blink(led_pin):
	"""
	Blinks the LED pin passed into function
	"""
	for i in range(3):
		GPIO.output(led_pin, GPIO.LOW)
		time.sleep(0.5)
		GPIO.output(led_pin, GPIO.HIGH)
		time.sleep(0.5)

def open_chute(pwm_obj):
	""" 
 	Opens the package chute door 
  	"""
	led_blink(BLED_PIN)
	GPIO.output(BLED_PIN, 1)

	for i in range(0,62,2):
                servo_write(i,pwm_obj)
                time.sleep(0.1)

def close_chute(pwm_obj):
	""" 
 	Closes the package chute door
  	"""
	led_blink(BLED_PIN)
	GPIO.output(BLED_PIN, 0)

	for i in range(60,-2,-2):
                servo_write(i,pwm_obj)
                time.sleep(0.1)

def unlock_door(pwm_obj):
	""" 
 	Unlocks the deadbolt on the door
  	"""
	servo_write(135,pwm_obj)

	led_blink(GLED_PIN)
	GPIO.output(GLED_PIN, 1)

def lock_door(pwm_obj):
	""" 
 	Locks the deadbolt on the door
  	"""
	led_blink(GLED_PIN)
	GPIO.output(GLED_PIN, 0)

	servo_write(0,pwm_obj)

def chute_activation(pwm_obj):
	time.sleep(0.2)
	open_chute(pwm_obj)
	time.sleep(5)
	print("sensing movement...")
	sense_movement()
	close_chute(pwm_obj)
	print("finished")

def lock_activation(pwm_obj):
	time.sleep(0.2)
	print("locking door")
	unlock_door(pwm_obj)
	time.sleep(3)
	print("locking door")
	lock_door(pwm_obj)
	print("finished")

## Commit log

2023-10-20 FPS Code(if needed)
    This is the code used to create the separate threading for the camera. PiCameraFPS is a test file to run, this will show how the multi threading process can improve our systems performance
2023-10-26 Create thread_demo.py(This will run FPS and WebStream to show results
2023-10-26 Add files via upload
    UPDATES from servocontro.py - more organized code
2023-10-31 Add files via upload
    Added a new file to show how I installed Opencv, Keras, and Tensorflow onto the raspberry pi. Enjoy! :)
2024-03-27 Add PCBFILES to repository
    [PowerBoost_PCB-B_Cu.gbr, PowerBoost_PCB-B_Mask.gbr, PowerBoost_PCB-B_Paste.gbr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]
2024-03-27 PCB Design Files
    [PowerBoost_PCB.kicad_pcb, PowerBoost_PCB.kicad_sch]
2024-03-27 PCB Manufature
    [PowerBoost_PCB-B_Cu.gbr, PowerBoost_PCB-B_Mask.gbr, PowerBoost_PCB-B_Paste.gbr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]
2024-04-10 Add files via upload
    threaded files
